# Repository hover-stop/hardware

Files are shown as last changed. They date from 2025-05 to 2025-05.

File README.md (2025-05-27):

# HSI Mk1 Hardware Repository

This repository contains the hardware design files for the HoverStop project. It includes part files, metadata, and utility scripts to manage and validate the hardware components.

---

## Documentation

For detailed design guidelines, part requirements, and contribution processes, please visit our [documentation site](https://hover-stop.github.io/docs/).

---

## Repository Structure

Each part is stored in its own folder named with a 5-digit part number. The folder contains:

- Design files (e.g., `.step`, `.3mf`)
- `metadata.yaml` file with part details
- Optional `REQUIREMENTS.md` file for part-specific requirements

---

## Utility Scripts

The `utils/` directory contains scripts to automate common tasks:

- **`cli_new_part.py`**: Automates the creation of new part directories with unique part numbers.
- **`cli_make_bom.py`**: Generates a Bill of Materials (`BOM.md`) from all `metadata.yaml` files.
- **`cli_validate_metadata.py`**: Validates `metadata.yaml` files against a defined schema.

Refer to the `utils/README.md` file for setup and usage instructions.

---

## Contribution Workflow

1. Create a new branch for your changes.
2. Use `cli_new_part.py` to add new parts.
3. Validate your changes with `cli_validate_metadata.py`.
4. Generate the BOM using `cli_make_bom.py`.
5. Submit a pull request for review.

---

## Communication

All major updates and discussions are coordinated via Discord. For questions or support, please reach out to the team.

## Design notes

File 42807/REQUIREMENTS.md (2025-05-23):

# Requirements for 42807 - Case Adapter (formerly "Mounting Tray" / "Purple Brace")

This document outlines the key design and functional requirements for the **Case Adapter** (Part Number 42807), previously referred to as the "mounting tray" or "purple brace". This adapter is used only when the HSI Mk.1 throttle is enclosed within the HSI case, and serves as the interface between the throttle base plate and the case walls.

## Functional Requirements

1. **Case-to-Throttle Interface:** Shall provide a structural interface between the HSI Mk.1 **Base Plate** (to which all throttle components are mounted) and the **case walls**, enabling the throttle to be enclosed.
2. **Used Only with Case:** This adapter is only used when the throttle is mounted **within the HSI case**. It is not compatible with DZUS rail mounting or standalone tray installations.
3. **Supports Base Plate:** Provides support under the **Base Plate**, but does not directly attach to the throttle internals (`96784 - Body Assembly`)—only the plate beneath them.
4. **Serviceability:** Must allow for installation and removal of the base plate and case walls without damage or interference.
5. **Clearance for Components:** Must allow adequate clearance beneath the base plate for connectors, wiring, or hardware.

## Physical & Manufacturing Requirements

1. **3D Printability:** Must be manufacturable as a single 3D-printed part on a print bed of at least 256x256mm.
2. **Material:** Recommended materials include PETG, ABS, or similar with sufficient structural rigidity.
3. **Dimensional Fit:** Must align with the base plate footprint and internal volume defined by the `77875 - Ghost Volume, Throttle Body`.

## Assembly & Hierarchy

1. **Parent Assembly:** Component of `62988 - HSI Mk.1 Mounting Kit`.
2. **Mounting Method:** Attaches between the **Base Plate** and the **case walls**, enabling enclosure use only.

## Naming and Clarification

* This part shall be referred to as the **Case Adapter**.
* It is **not** to be confused with the **Base Plate**, which directly supports the throttle hardware.
* It is **not** used in installations involving:
  - **DZUS rails**
  - **Standalone trays**
  - **Direct mounting to a cockpit panel or desktop**

## Exclusions

* Not used when the HSI Mk.1 throttle is mounted using DZUS rails.
* Not used when mounted to a standalone tray or open frame.
* Not a substitute for the Base Plate or Body Assembly.

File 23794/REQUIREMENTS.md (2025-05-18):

# Requirements for 23794 - Angle Sensor, Hall Effect

This document outlines the key design and functional requirements for the P3022 Hall Effect Angle Sensor (Part Number 23794).

## Functional Requirements

1. **Measurement Function:** Must provide precise, non-contact rotary position measurement for the throttle axes.
2. **Sensing Range:**
   * Primary Option (P3022C360V1T): 0-360° continuous rotation measurement
   * Alternative Option (P3022C90V1T): 0-90° limited rotation measurement
3. **Output Characteristics:**
   * Signal Type: Analog voltage output proportional to angle
   * Resolution: High precision, suitable for flight control input detection
   * Response Time: Fast enough for real-time flight simulator control input
4. **Electrical Specifications:**
   * Supply Voltage: Compatible with controller board (typically 5V DC)
   * Output Range: 0-5V proportional voltage output
   * Current Consumption: Low power consumption suitable for extended operation

## Physical & Manufacturing Requirements

1. **Form Factor:** Miniature size to fit within confined throttle mechanism spaces
2. **Mounting Interface:** 
   * Must be mechanically compatible with the HSI Mk.1 throttle axis mounting points
   * Installation must allow proper alignment with the rotation axes
3. **Dimensions:** As per P3022 series specifications
4. **Shaft/Magnet Interface:** Compatible with the throttle control axes

## Durability & Performance Requirements

1. **Lifespan:** Minimum 100,000 rotation cycles without calibration drift
2. **Mechanical Durability:** 
   * No-contact measurement to prevent mechanical wear
   * Shaft bearings (if applicable) must support smooth operation
3. **Temperature Range:** Suitable for indoor operation (0°C to 50°C minimum)
4. **Linearity:** High linearity across the measurement range

## Integration Requirements

1. **Electrical Interface:** Compatible with the HSI Mk.1 controller board
2. **Wiring:** Standardized connector or wire leads for integration with the `81137 - Wiring Harness`
3. **Calibration:** Easily calibratable in-situ 
4. **Mechanical Integration:**
   * Must be installable on all three measurement axes (throttle, nozzle position, and friction control)
   * Mounting orientation must be consistent with the sensor's measurement plane

## Usage Applications

These sensors will be installed in the following control axes:
1. Main throttle position measurement
2. Nozzle position control measurement
3. Possibly friction control or other auxiliary axis measurement

## Assembly & Hierarchy

1. **Parent Assembly:** This part is a component of `51364 - Sensors Kit`
2. **Quantity per Assembly:** 3 units (one per axis of measurement)
3. **Installation Sequence:** To be installed during final assembly of the respective control mechanisms

## Sourcing Options

1. **Primary Source:** CALT P3022C360V1T from manufacturer website (https://caltsensor.com/product/miniature-non-contact-angle-sensor-p3022-series/)
2. **Secondary Source:** Alternative supplier via Amazon (https://a.co/d/a8b02RU)
3. **Alternatives:** The P3022C90V1T may be substituted if the 360-degree measurement range is not required for a particular axis

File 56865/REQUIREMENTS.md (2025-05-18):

# Requirements for 56865 - Toggle Switch, 2 Position

This document outlines the key design and functional requirements for the Toggle Switch (Part Number 56865).

## Functional Requirements

1. **Switch Type:** 2-position maintained toggle switch
2. **Electrical Specifications:**
   * Configuration: SPST-NO (Single Pole, Single Throw, Normally Open)
   * Current Rating: 6A minimum
   * Number of Terminals: 2

3. **Function-Specific Requirements:**
   * **When Used for Manual Fuel Control:**
     * 2-Position Lever Lock Toggle
     * Release Force: 3-6 lb
     * Operating Force: 8 lb maximum
     * Actuation Angle: 21.5° ± 0.06°

   * **When Used for Jet Pipe Temp Limit (JPTL):**
     * 2-Position Toggle Switch
     * Operating Force: 28 oz + 8 oz (36 oz maximum)
     * Actuation Angle: 16° ± 1°

## Physical & Manufacturing Requirements

1. **Form Factor:** Round toggle
2. **Material:** Per manufacturer specification, suitable for cockpit environment
3. **Mounting:** Panel mount compatible with standard cockpit panel thickness
4. **Durability:** Must withstand repeated actuations without degradation of performance

## Interfacing Requirements

1. **Electrical Connection:** Compatible with standard aircraft electrical systems
2. **Panel Integration:** Must conform to standard panel cutout dimensions
3. **Terminal Accessibility:** Terminals must be accessible for secure wire connection

## Environmental Requirements

1. **Operating Temperature Range:** Suitable for cockpit environment (-20°C to +70°C)
2. **Humidity Resistance:** Capable of operation in varying humidity conditions

## Alternatives & Sourcing

1. **Commercial Alternative:** 
   * McMaster-Carr 7343K184 or Digikey TA2-1A-DC-5 
   * These parts are interchangeable for both functions

2. **MIL-SPEC Alternatives:** 
   * For Jet Pipe Temp Limit (JPTL): MS24523-22
   * For Manual Fuel Control: MS24658-22G
   * Note: MIL-SPEC parts are not interchangeable between functions

## Assembly & Hierarchy

1. **Parent Assembly:** This part is a component of `51364 - Sensors Kit`
2. **Quantity per Assembly:** 2 units (one for Manual Fuel Control, one for JPTL)

## Compliance

1. **Standards:** Should meet or exceed the requirements from the Air Crew Stations specification document
2. **Ergonomic Performance:** Operating forces and actuation angles must match specifications to provide authentic simulator control feel

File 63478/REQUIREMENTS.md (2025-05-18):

# Requirements for 63478 - Toggle Switch, 3 Position

This document outlines the key design and functional requirements for the 3-Position Toggle Switch (Part Number 63478).

## Functional Requirements

1. **Switch Type:** 3-position momentary toggle switch
2. **Electrical Specifications:**
   * Configuration: DPDT (Double Pole, Double Throw)
   * Current Rating: 6A minimum
   * Voltage Rating: 28VDC
   * Number of Terminals: 6

3. **Function-Specific Requirements for Rudder Trim:**
   * Momentary return to center (spring-loaded)
   * Operating Force: 20-24 oz
   * Actuation Angle: 17° ± 1° each side from center position
   * Center detent force: 8-10 oz
   * Return-to-center spring force: Must return to center position when released from either extreme

## Physical & Manufacturing Requirements

1. **Form Factor:** Round toggle with IP67 rating
2. **Material:** Per manufacturer specification, suitable for cockpit environment
3. **Mounting:** Panel mount compatible with standard cockpit panel thickness (0.125" - 0.187")
4. **Durability:** Must withstand 100,000 actuations minimum without degradation of performance

## Interfacing Requirements

1. **Electrical Connection:** Solder lugs or quick-connect terminals
2. **Panel Integration:** 0.5" (12.7mm) mounting hole
3. **Terminal Accessibility:** Terminals must be accessible for secure wire connection
4. **Labeling:** Must accommodate NOSE UP/NOSE DOWN labeling on panel

## Environmental Requirements

1. **Operating Temperature Range:** -30°C to +85°C
2. **Humidity Resistance:** IP67 rated or equivalent
3. **Vibration Resistance:** Must maintain functionality under typical cockpit vibration conditions

## Alternatives & Sourcing

1. **Commercial Alternative:** 
   * McMaster-Carr 6D1-003
   * Digikey 3-position momentary toggle switch with DPDT configuration
   * These parts must be verified for correct return-to-center spring functionality

2. **MIL-SPEC Alternative:** 
   * MS24524-27
   * Note: This is the original specification part used in aircraft

## Assembly & Hierarchy

1. **Parent Assembly:** This part is a component of `51364 - Sensors Kit`
2. **Quantity per Assembly:** 1 unit (for Rudder Trim control)

## Compliance

1. **Standards:** Should meet or exceed the requirements from the Air Crew Stations specification document
2. **Ergonomic Performance:** Operating forces and actuation angles must match specifications to provide authentic simulator control feel
3. **Operational Feel:** Must provide positive tactile feedback when moved away from center position

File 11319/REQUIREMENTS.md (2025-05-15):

# Requirements for 11319 - Throttle Body Bottom Plate

This document outlines the key design and functional requirements for the Throttle Body Bottom Plate (Part Number 11319).

## Functional Requirements

1.  **Structural Base:** Shall serve as the primary structural base for the `96784 - HSI Mk.1 Body Assembly`.
2.  **Component Mounting:** Must provide robust and accurate mounting points for:
    *   Top facia panels.
    *   Internal throttle mechanisms (e.g., lever assemblies, sensors, friction systems).
    *   Any other components directly part of the core throttle body.
3.  **Load Bearing:** Must be capable of supporting the loads exerted by user operation of the throttle controls and the weight of attached components.
4.  **Serviceability:** Design should allow for access to and servicing of internal components attached to this plate.

## Physical & Manufacturing Requirements

1.  **Primary Manufacturing Process:** Intended to be `3D Printed` (as per metadata). Alternative manufacturing considerations can be noted if applicable.
2.  **Material:** To be specified (e.g., PETG, ABS, PLA+ with sufficient strength and rigidity).
3.  **Dimensional Stability:** Must maintain dimensional accuracy to ensure proper fit and alignment of all attached parts and external mounting interfaces.
4.  **Heat Resistance:** If in proximity to electronics or other heat sources, material selection should consider heat resistance.

## Interfacing & Mounting Requirements

This plate is designed for versatile mounting and must provide features to interface with the following (mutually exclusive mounting methods):

1.  **Enclosure Mounting (via `42807 - Mounting Tray`):**
    *   Shall provide defined mounting points (e.g., holes, bosses) to securely attach to the `42807 - Mounting Tray` (the "purple brace").
    *   These mounting points must align with the corresponding features on the `42807 - Mounting Tray`.
2.  **DZUS Rail Mounting:**
    *   Shall incorporate features compatible with standard DZUS rails for direct mounting (if this option is chosen).
    *   This may include specific hole patterns, thicknesses, or edge features.
3.  **Custom Flat Panel Mounting:**
    *   Shall provide a pattern of mounting holes (e.g., 6 or more, as per Xpendable's notes) allowing it to be screwed down onto a custom flat surface (e.g., wood, MDF, metal plate).
    *   These holes should be accessible from the top (through the facia or before facia installation).
    *   The design should consider necessary cutouts in the custom panel for throttle mechanism clearance, mimicking openings in the `42807 - Mounting Tray`.

## Assembly & Hierarchy

1.  **Parent Assembly:** This part is a critical component of `96784 - Body Assembly`.
2.  **Fastening Methods:** Should utilize appropriate fastening methods for all attached components (e.g., heat-set inserts for machine screws, self-tapping screws for plastic if suitable, through-holes for bolts).

## Design Considerations

*   Minimize weight while maintaining structural integrity.
*   Ensure clearance for all moving parts of the throttle mechanisms.
*   Consider wire routing and management if electronics are mounted directly or pass through.

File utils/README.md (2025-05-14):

# Utility Scripts

This directory contains utility scripts to help manage and automate tasks within the hardware project.

## Environment Setup (One-time)

Before running any utility scripts for the first time, you need to set up a Python virtual environment and install the required packages. This ensures that the scripts run in an isolated environment with the correct dependencies.

1.  **Open your terminal or command prompt.**
2.  **Navigate to the `utils` directory** within this project:
    ```sh
    cd path\to\hardware\utils
    ```
3.  **Create the virtual environment:**
    ```sh
    python -m venv .venv
    ```
    This will create a new folder named `.venv` in the `utils` directory.
4.  **Activate the virtual environment:**
    *   On Windows (PowerShell):
        ```powershell
        .\.venv\Scripts\Activate.ps1
        ```
    *   On Windows (Command Prompt):
        ```cmd
        .\.venv\Scripts\activate.bat
        ```
    *   On macOS and Linux:
        ```sh
        source .venv/bin/activate
        ```
    Your terminal prompt should change to indicate that the virtual environment is active (e.g., `(.venv) ...`).
5.  **Install required packages:**
    With the virtual environment active, run the following command to install the necessary Python libraries:
    ```sh
    pip install PyYAML jsonschema
    ```

You only need to perform these setup steps once. For subsequent uses, you just need to activate the virtual environment (step 4) before running a script.

## `cli_new_part.py`

### Purpose

The `cli_new_part.py` script is a command-line tool designed to streamline the creation of new part entries in this repository. It automates the process of:

1.  Generating a unique 5-digit part number.
2.  Creating a new directory for the part, named with this part number.
3.  Generating a `metadata.yaml` file within the new part directory, pre-filled with information provided by the user via interactive prompts.

This helps ensure consistency and reduces manual effort when adding new hardware components.

### How to Use

1.  **Open your terminal or command prompt.**
2.  **Navigate to the `utils` directory** within this project:
    ```sh
    cd path\to\hardware\utils
    ```
3.  **Activate the Python virtual environment** (if not already active):
    *   On Windows (PowerShell):
        ```powershell
        .\.venv\Scripts\Activate.ps1
        ```
    *   On Windows (Command Prompt):
        ```cmd
        .\.venv\Scripts\activate.bat
        ```
    *   On macOS and Linux:
        ```sh
        source .venv/bin/activate
        ```
4.  **Run the script** using Python:
    ```sh
    python cli_new_part.py
    ```
5.  **Follow the prompts:** The script will ask you for various details about the new part, such as owner, name, description, etc. Provide the information as requested.
6.  Once all information is gathered, the script will create the new part directory and its `metadata.yaml` file in the main `hardware` directory (one level above `utils`).
7.  **Deactivate the virtual environment** when you are done (optional but good practice):
    ```sh
    deactivate
    ```

Example: If the script generates part number `12345`, it will create a directory `../12345/` and `../12345/metadata.yaml`.

## `cli_validate_metadata.py`

### Purpose

The `cli_validate_metadata.py` script is a command-line tool used to validate all `metadata.yaml` files within the project against a defined schema. This helps ensure consistency and correctness of the metadata across all parts.

The script checks for:
1.  Correct YAML format.
2.  Adherence to a predefined schema (e.g., required fields, correct data types, allowed values for certain fields like `status` and `part_type`).
3.  Consistency between the `part_number` field in the `metadata.yaml` file and its parent directory name.

### How to Use

1.  **Ensure `jsonschema` is installed:** If you haven't already, install it with the virtual environment active:
    ```sh
    pip install jsonschema
    ```
2.  **Open your terminal or command prompt.**
3.  **Navigate to the `utils` directory** within this project:
    ```sh
    cd path\to\hardware\utils
    ```
4.  **Activate the Python virtual environment** (if not already active - see Environment Setup).
5.  **Run the script** using Python:
    ```sh
    python cli_validate_metadata.py
    ```
6.  The script will output the validation status for each `metadata.yaml` file found. If errors are present, they will be detailed, indicating the file, the location of the error within the file, and the nature of the error.
7.  A summary of the validation results will be printed at the end.
8.  **Deactivate the virtual environment** when you are done (optional but good practice):
    ```sh
    deactivate
    ```

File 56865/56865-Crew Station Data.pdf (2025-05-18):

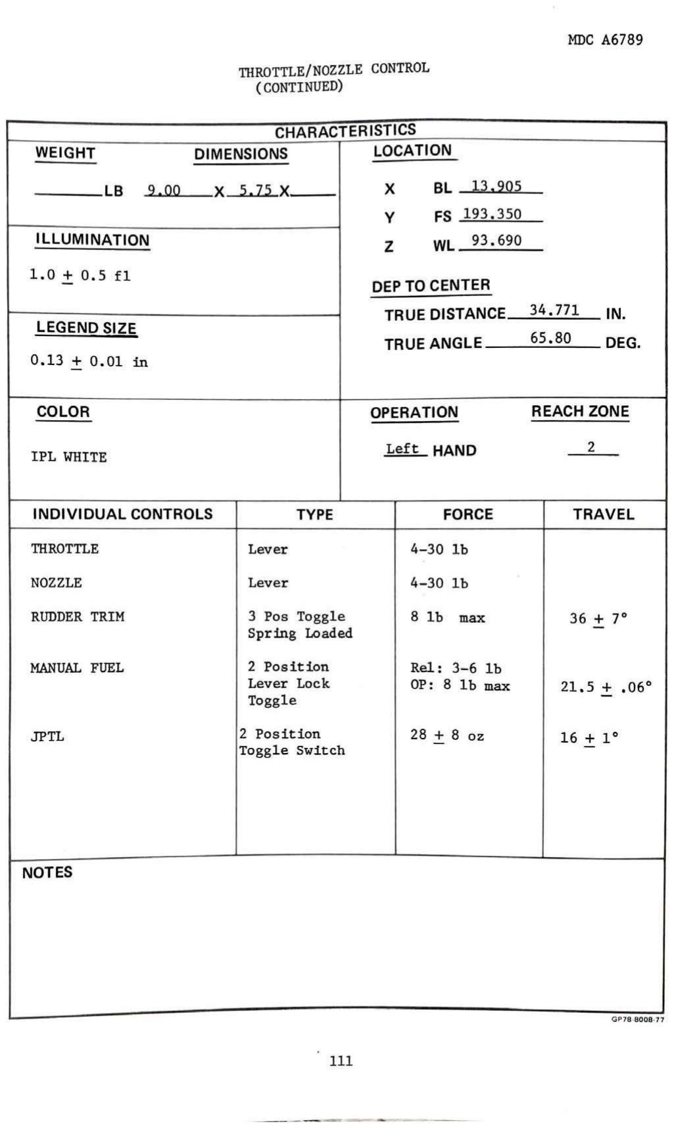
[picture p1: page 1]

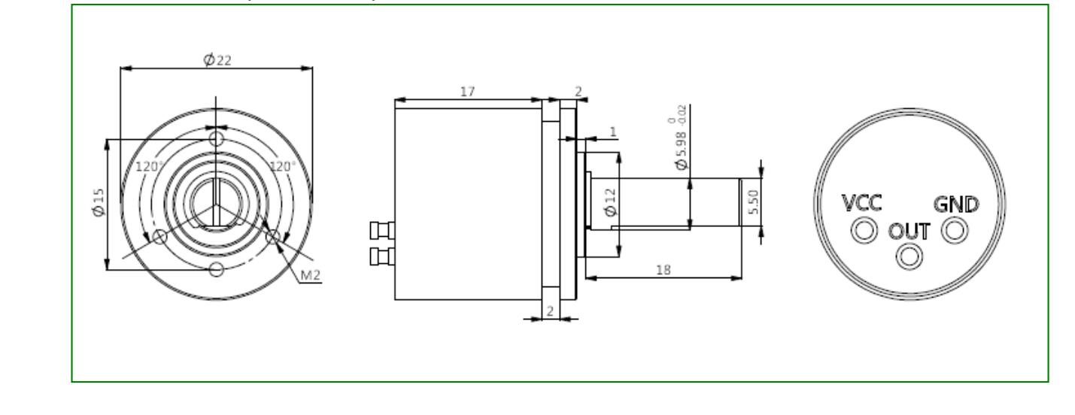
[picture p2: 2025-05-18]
23794/P3022C360V1T.jpg

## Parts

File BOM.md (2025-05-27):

<!-- 
THIS FILE IS AUTO-GENERATED BY THE cli_make_bom.py SCRIPT.
DO NOT EDIT THIS FILE MANUALLY. YOUR CHANGES WILL BE OVERWRITTEN.
-->

# Bill of Materials

Generated on: 2025-05-26

| Part Number | Name | Description | Qty | Part Type | Primary Source | Cost | Owner | Status |
| --- | --- | --- | --- | --- | --- | --- | --- | --- |
| 11117 | Electronics Assembly | Assembly of all electronic components, sensors, controllers, and wiring harnesses for the HSI Mk.1. | 1 | Assembly | In-house design | TBD | Engines | Draft |
| 11319 | Throttle Body Bottom Plate | Structural base of the HSI Mk.1 throttle body. Top facia panels and internal mechanisms attach to this plate. Designed for multiple mounting options: via 42807 Mounting Tray (for enclosures), DZUS rails, or custom flat panel. | 1 | 3D Printed | In-house design | TBD | Xpendable | Draft |
| 12574 | Hex Head Screw, M4 x 20 mm, Class 8.8, Zinc-Plated Steel | M4 × 20 mm hex-head screw, Class 8.8 steel, fully threaded (M4-0.7 mm, Class 6h, right-hand). Head width 7 mm, height 2.8 mm; ISO 4017 / DIN 933 compliant. Zinc-plated finish for mild corrosion resistance; 110 000 psi tensile strength, Rockwell C21 hardness. Cost ≈ /usr/bin/bash.02 ea (pack of 100). RoHS 3 and REACH compliant. | 6 | Off The Shelf | https://www.mcmaster.com/91280A140/ | TBD | Engines | Draft |
| 14619 | Ghost Volume, Throttle Body, Inner | A ghost part that represents the inside limits for the throttle body desgin. | 1 | Ghost | Unknown | $0.00 | Xpendable | Prototype |
| 18923 | Spur Gear, Sensor | The small spur gear that attaches to the angle sensor.  This is driven by the levers.  It has a modulus of 0.8mm and 22 teeth. | 1 | 3D Printed | Unknown | TBD | Engines | Draft |
| 18924 | Throttle Grip Comms Switch Center Button | Center button of the comms-rocker-switch of the throttle grip, designed for either 3D printing or CNC machining | 1 | 3D Printed | In-house prototype | TBD | Kurisu | Draft |
| 22357 | Support Frame, Throttle | This is the main supporting frame that locates and retains the throttle mechanism. | 1 | 3D Printed | Unknown | TBD | Engines | Draft |
| 22358 | Throttle Grip Comms Switch Rocker Switch | Rocker-switch for the comms-switch of the throttle grip, designed for either 3D printing or CNC machining | 1 | 3D Printed | In-house prototype | TBD | Kurisu | Draft |
| 23794 | Angle Sensor, Hall Effect | CALT P3022C360V1T (alt P3022C90V1T) miniature non-contact hall effect angle sensor for precision rotary position measurement. Used for axis position sensing in the HSI Mk.1. | 3 | Electronics | https://caltsensor.com/product/miniature-non-contact-angle-sensor-p3022-series/ | TBD | Engines | Release |
| 28175 | Brush, Throttle | Brush strip used to seal the opening in the throttle body where the throttle lever protrudes. | 2 | Off The Shelf | https://www.mcmaster.com/74405T1-74405T109/ | $2.75 | Engines | Release |
| 31074 | Angle Sensor, Retaining Plate | This is the plate that retains the attachment plate of the angle sensor in the throttle support frame | 1 | 3D Printed | Unknown | TBD | Engines | Draft |
| 31612 | Flat Head Screw, M8 x 25 mm, Zinc-Plated Steel | M8 × 25 mm flat-head Phillips screw, zinc-plated steel, fully threaded (M8-1.25, Class 6h, right-hand). Head Ø 14.5 mm, head height 4 mm, 90 ° countersink, DIN 965 compliant, 60 000 psi tensile strength. Provides mild corrosion resistance; RoHS 3 and REACH compliant. | 2 | Off The Shelf | https://www.mcmaster.com/91420A530/ | $0.40 | Engines | Draft |
| 32001 | Grip Chassis Part 1 | Main chassis body for the throttle grip designed for either 3D printing or CNC machining | 1 | 3D Printed | In-house prototype | TBD | Kurisu | Draft |
| 32002 | Grip Chassis Part 2 | Second part of the main chassis body for the throttle grip designed for either 3D printing or CNC machining | 1 | 3D Printed | In-house prototype | TBD | Kurisu | Draft |
| 35582 | Angle Sensor, Attachment Plate | The moving plate that retains the angle sensor when it is mounted to the frame assembly. | 1 | 3D Printed | Unknown | TBD | Engines | Draft |
| 39780 | Pan Head Screw, M4 x 30 mm, Zinc-Plated Steel | M4 x 30 mm pan head Phillips screw, zinc-plated steel, fully threaded, DIN 7985 and ISO 7045 compliant. Provides mild corrosion resistance. | 1 | Off The Shelf | https://www.mcmaster.com/92005A232/ | TBD | Engines | Draft |
| 41464 | Friction Cam Lever, Drum Brake, 3D-Printed | 3D-printed cam lever that pivots to press the brake shoes against the 66-tooth drum gear. Material: PETG or PA-CF, 4 perimeters, 40 % gyroid infill. | 2 | 3D Printed | In-house additive manufacturing | TBD | Engines | Draft |
| 42807 | Case Adapter | Case adapter (purple brace) for securing the HSI Mk.1 Body Assembly (96784) to a case. | 1 | 3D Printed | In-house design | TBD | Xpendable | Draft |
| 45193 | Wool Felt Strip, F1, 1/16" × 1/2" × 10 ft | Firm wool felt strip, Grade F1 (95 % wool). Dimensions: 1/16 in (1.6 mm) thick × 1/2 in (12.7 mm) wide × 10 ft long. Density 1 lb/yd², durometer 35A ±5, compressive load 21 psi at 10 % strain. Plain backing, off-white, –80 °F to +200 °F service, 500 psi tensile strength. Used as friction shoe lining; provides good wear and vibration damping. Cost ≈ .23 each. RoHS 3 and REACH compliant. | 1 | Off The Shelf | https://www.mcmaster.com/5051K152/ | $0.23 | Engines | Draft |
| 48793 | Spur Gear, 66 T, Drum Brake | 66-tooth spur gear (module 1.0, 20° pressure angle, 140 mm pitch Ø ≈ 70 mm pitch radius). 3 mm drum band on OD for printed friction brake shoe. Material: PETG or PA-CF, 3D-printed, face width 10 mm, reamed Ø12 mm bore with M4 setscrew flat. | 1 | 3D Printed | In-house additive manufacturing | TBD | Engines | Draft |
| 51364 | Sensors Kit | Collection of sensors used in the HSI Mk.1, including hall effect potentiometers for axis position sensing. | 1 | Assembly | In-house design | TBD | Engines | Draft |
| 56865 | Toggle Switch, 2 Position | 2-position, round, maintained, SPST-NO toggle switch with 2 terminals, 6A rating. Used for Jet Pipe Temp Limit (JPTL) and Manual Fuel Control functions in the HSI Mk.1. | 2 | Electronics | https://www.mcmaster.com/7343K184/ | 8.96 | Engines | Release |
| 57832 | Grip Assembly | Complete assembly for the HSI Mk.1 grip | 1 | Assembly | Unknown | TBD | Kurisu | Draft |
| 57833 | Throttle Grip Analog Stick Backing Plate | Backing plate to hold the analog stick of the throttle grip in place, designed for either 3D printing or CNC machining | 1 | 3D Printed | In-house prototype | TBD | Kurisu | Draft |
| 60550 | Nut, Locking, M8 | Low strength steel, zinc plated nyloc nut for M8x1.25 threads | 1 | Off The Shelf | https://www.mcmaster.com/90631A115/ | $0.10 | Engines | Release |
| 62146 | HoverStop HSI Mk.1 | The parent assembly for the HoverStop HSI Mk.1 throttle interface unit. | 1 | Assembly | Unknown | TBD | Engines | Draft |
| 62147 | Throttle Grip Side Button Backing Plate | Backing plate for the side buttons of the throttle grip, designed for either 3D printing or CNC machining | 1 | 3D Printed | In-house prototype | TBD | Kurisu | Draft |
| 62988 | Mounting Kit | Optional mounting kit for installing the HSI Mk.1 throttle (via its Body Assembly) into an enclosure. Includes the mounting tray (42807) and any associated hardware for this specific mounting method. | 1 | Assembly | In-house design | TBD | Xpendable | Draft |
| 63478 | Toggle Switch, 3 Position | 3-position, rounded, momentary, DPDT toggle switch with IP67 rating. Used for the Rudder Trim control in the HSI Mk.1. | 1 | Electronics | https://www.mcmaster.com/8002K116/ | 18.13 | Engines | Release |
| 67367 | Dzus Rail | Quick release mounting rail for Dzus fasteners | 2 | Off The Shelf | Unknown | TBD | Xpendable | Draft |
| 69806 | Bits Kit | All screws, nuts, rivets, inserts, and other consumables necessary to build the HSI Mk.1 | 1 | Assembly | Unknown | TBD | Engines | Draft |
| 74933 | Friction Shoe | Friction shoe that fits inside the friction spur gear. | 4 | 3D Printed | Unknown | TBD | Engines | Draft |
| 77875 | Ghost Volume, Throttle Body, Outer | A ghost part that represents the outside limits for the throttle body design. | 1 | Ghost | Unknown | $0.00 | Xpendable | Prototype |
| 77876 | Throttle Grip Comms Switch Backing Plate | Backing plate for the comms-rocker-switch of the throttle grip, designed for either 3D printing or CNC machining | 1 | 3D Printed | In-house prototype | TBD | Kurisu | Draft |
| 81137 | Wiring Harness | Complete wiring harness for connecting all electronic components and sensors in the HSI Mk.1. | 1 | Cable or Wire | In-house design | TBD | Engines | Draft |
| 87883 | Flat Head Screw, M4 x 10 mm, Zinc-Plated Steel | M4 x 10 mm flat head Phillips screw, zinc-plated steel, fully threaded, DIN 965 compliant. Provides mild corrosion resistance and is designed to sit flush in countersunk holes. | 4 | Off The Shelf | https://www.mcmaster.com/91420A220/ | TBD | Engines | Draft |
| 91686 | Controller Board | Main microcontroller board for the HSI Mk.1. Responsible for reading sensor inputs and communicating with the flight simulator software. | 1 | Electronics | In-house design | TBD | Engines | Draft |
| 94961 | Hex Nut, M4, Zinc-Plated Steel | Standard hex nut, M4 × 0.7 mm coarse thread (Class 6H, right-hand). Width 7 mm, height 3.2 mm. Low-strength zinc-plated steel (DIN 934); suitable for light-duty fastening. Provides mild corrosion resistance. Cost ≈ TBD ea (pack of 100). RoHS 3 and REACH compliant. | 1 | Off The Shelf | https://www.mcmaster.com/90591A141/ | TBD | Engines | Draft |
| 96784 | Body Assembly | The body assembly for the HSI Mk.1 | 1 | Assembly | Unknown | TBD | Xpendable | Draft |
| 98415 | Ghost Parts | A collector assembly for all ghost parts used in the HSI Mk.1 | 1 | Ghost | Unknown | TBD | Engines | Draft |

## Part Assembly Tree

```
62146 - HoverStop HSI Mk.1
├── 11117 - Electronics Assembly
│   ├── 51364 - Sensors Kit
│   │   ├── 23794 - Angle Sensor, Hall Effect
│   │   ├── 56865 - Toggle Switch, 2 Position
│   │   └── 63478 - Toggle Switch, 3 Position
│   ├── 81137 - Wiring Harness
│   └── 91686 - Controller Board
├── 57832 - Grip Assembly
│   ├── 32001 - Grip Chassis Part 1
│   │   └── 62147 - Throttle Grip Side Button Backing Plate
│   └── 32002 - Grip Chassis Part 2
│       ├── 18924 - Throttle Grip Comms Switch Center Button
│       ├── 22358 - Throttle Grip Comms Switch Rocker Switch
│       ├── 57833 - Throttle Grip Analog Stick Backing Plate
│       └── 77876 - Throttle Grip Comms Switch Backing Plate
├── 62988 - Mounting Kit
│   └── 67367 - Dzus Rail
├── 69806 - Bits Kit
│   ├── 12574 - Hex Head Screw, M4 x 20 mm, Class 8.8, Zinc-Plated Steel
│   ├── 31612 - Flat Head Screw, M8 x 25 mm, Zinc-Plated Steel
│   ├── 39780 - Pan Head Screw, M4 x 30 mm, Zinc-Plated Steel
│   ├── 60550 - Nut, Locking, M8
│   ├── 87883 - Flat Head Screw, M4 x 10 mm, Zinc-Plated Steel
│   └── 94961 - Hex Nut, M4, Zinc-Plated Steel
├── 96784 - Body Assembly
│   ├── 11319 - Throttle Body Bottom Plate
│   ├── 22357 - Support Frame, Throttle
│   │   ├── 18923 - Spur Gear, Sensor
│   │   ├── 28175 - Brush, Throttle
│   │   ├── 31074 - Angle Sensor, Retaining Plate
│   │   ├── 35582 - Angle Sensor, Attachment Plate
│   │   ├── 41464 - Friction Cam Lever, Drum Brake, 3D-Printed
│   │   ├── 45193 - Wool Felt Strip, F1, 1/16" × 1/2" × 10 ft
│   │   ├── 48793 - Spur Gear, 66 T, Drum Brake
│   │   └── 74933 - Friction Shoe
│   └── 42807 - Case Adapter
└── 98415 - Ghost Parts
    ├── 14619 - Ghost Volume, Throttle Body, Inner
    └── 77875 - Ghost Volume, Throttle Body, Outer
```

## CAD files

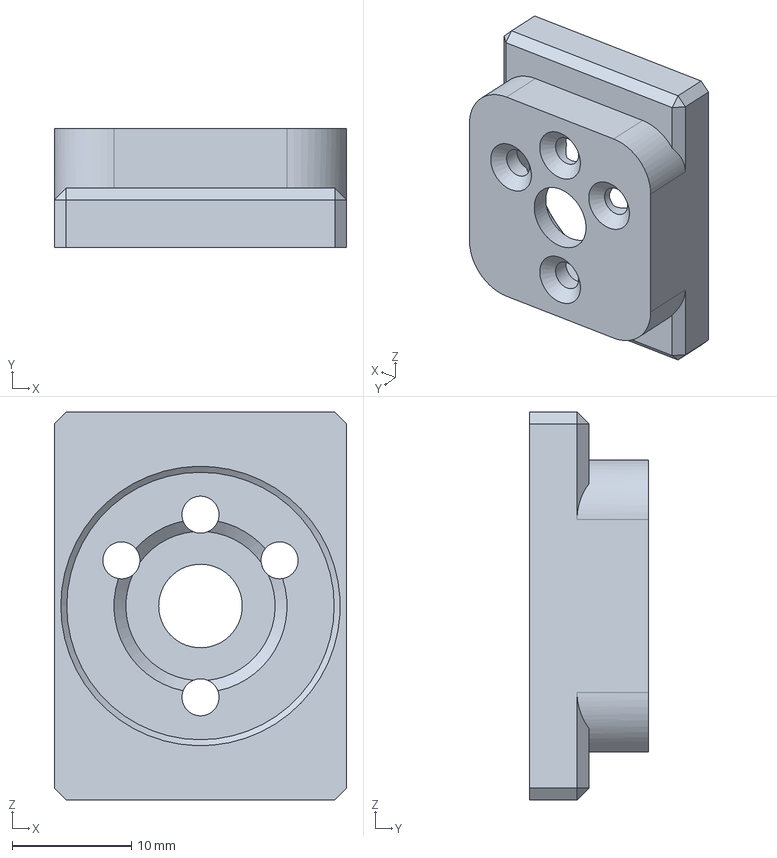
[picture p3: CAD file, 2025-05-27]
35582/Angle Sensor, Attachment Plate v2.step
24.5 x 10.0 x 32.5 mm

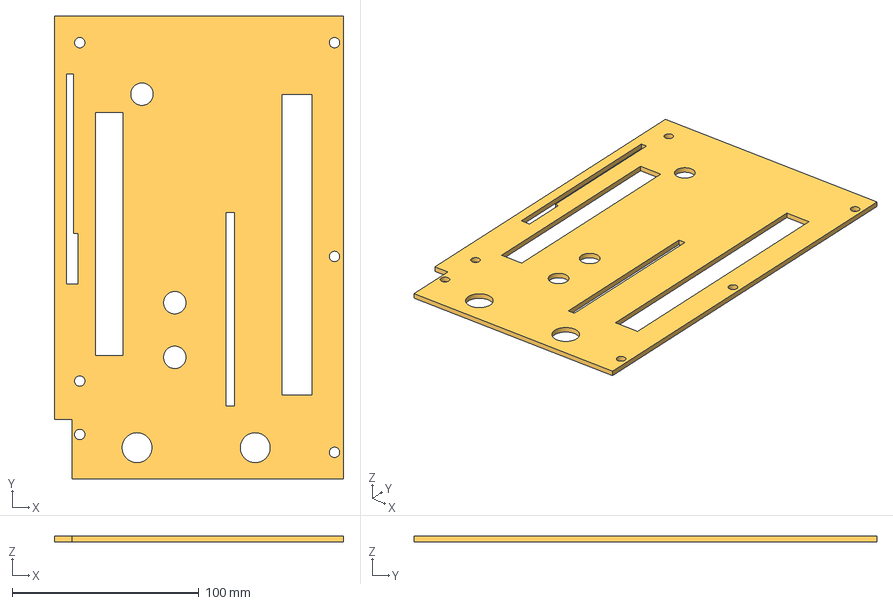
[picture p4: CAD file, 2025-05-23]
11319/11319 Throttle Body Bottom Plate.step
154.8 x 247.7 x 3.00 mm

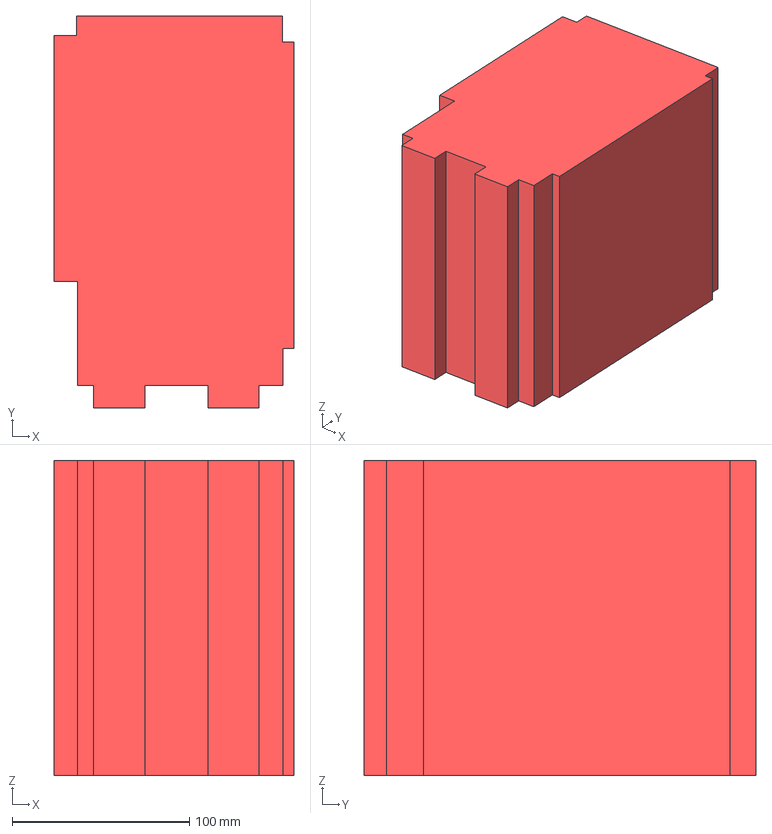
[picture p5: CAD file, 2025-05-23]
14619/14619 Ghost Volume, Throttle Body, Inner.step
135.3 x 221.3 x 177.8 mm

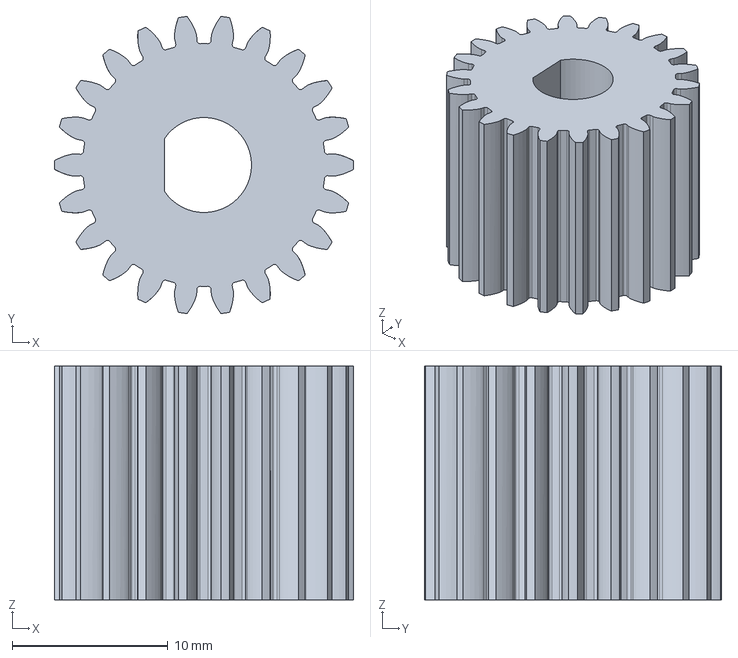
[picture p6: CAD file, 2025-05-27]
18923/18923 Spur Gear, Sensor.step
19.2 x 19.1 x 15.0 mm

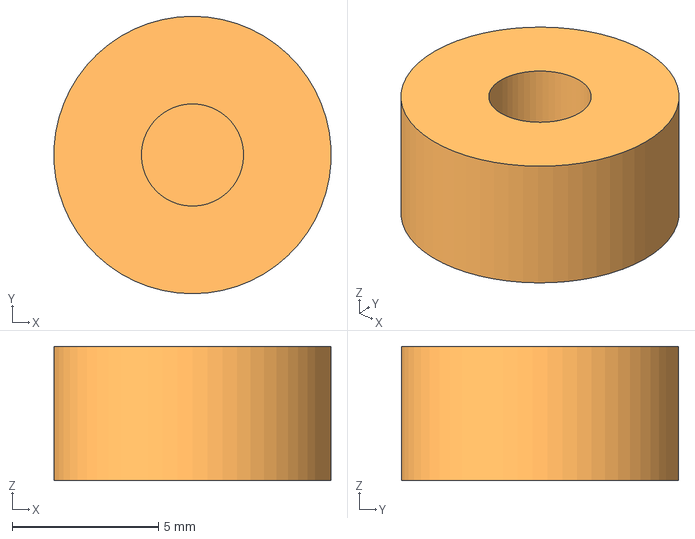
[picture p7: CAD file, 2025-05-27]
18924/18924 Throttle Grip Comms Switch Center Button.step
9.49 x 9.50 x 4.60 mm

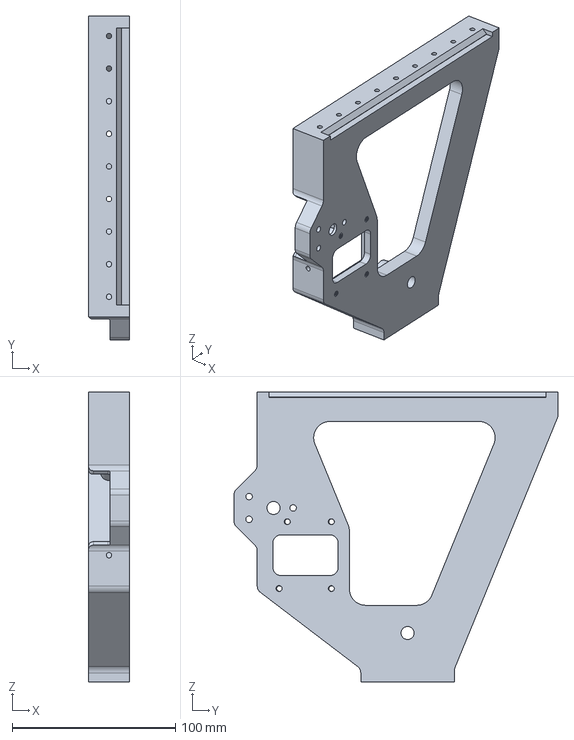
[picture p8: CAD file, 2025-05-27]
22357/22357 Support Frame, Throttle.step
25.0 x 198.8 x 177.8 mm

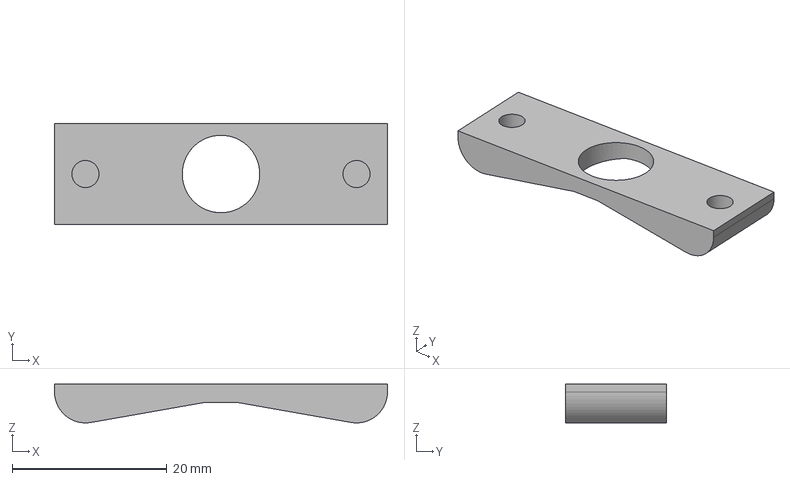
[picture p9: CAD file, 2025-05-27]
22358/22358 Throttle Grip Comms Switch Rocker Switch.step
43.0 x 13.0 x 5.02 mm

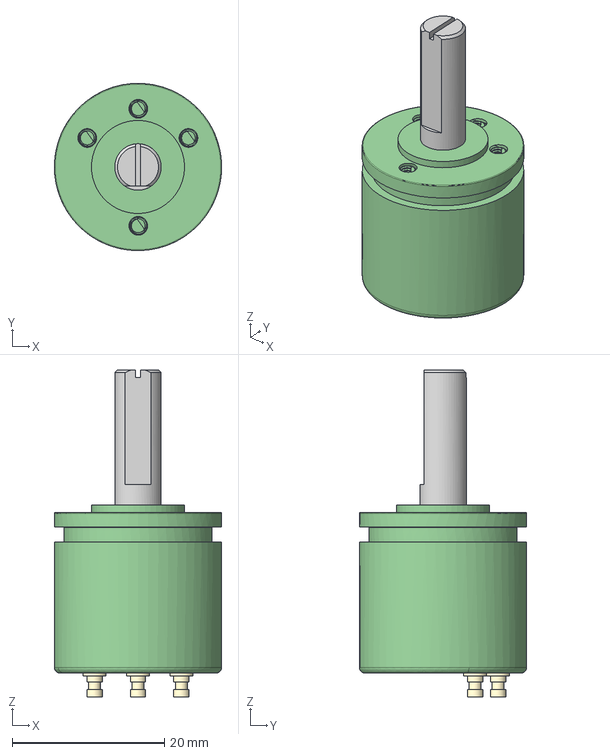
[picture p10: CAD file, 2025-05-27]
23794/23794-Angle Sensor, Hall Effect.step
22.0 x 22.0 x 43.0 mm

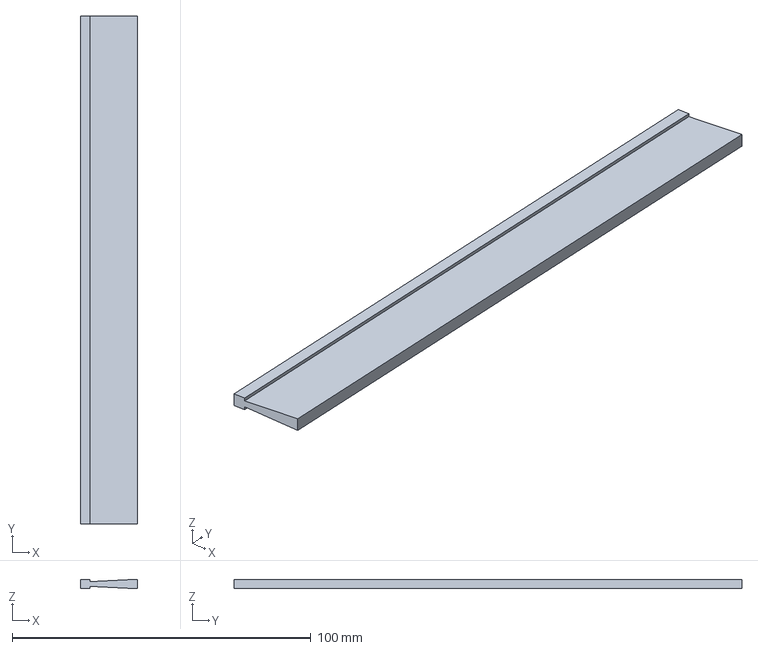
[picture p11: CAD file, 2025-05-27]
28175/28175 Brush, Throttle v1.step
19.1 x 170.0 x 3.18 mm

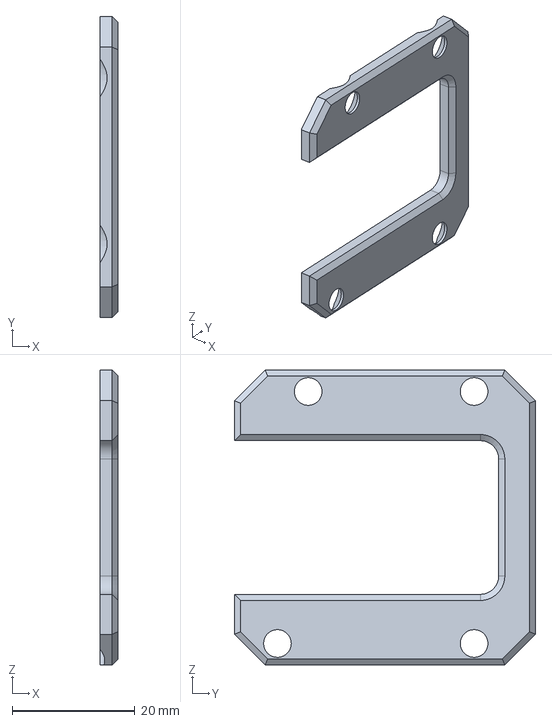
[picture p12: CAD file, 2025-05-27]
31074/31074 Angle Sensor, Retaining Plate.step
3.00 x 49.0 x 48.0 mm

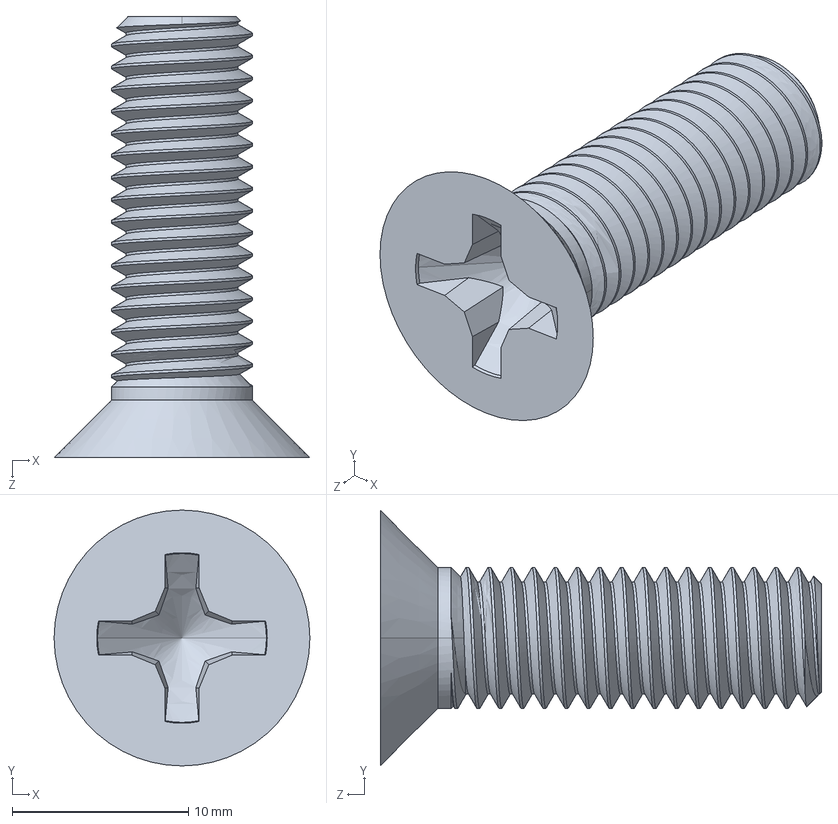
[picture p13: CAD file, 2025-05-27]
31612/31612 Flat Head Screw, M8 x 25 mm, Zinc-Plated Steel.STEP
14.5 x 14.5 x 25.0 mm

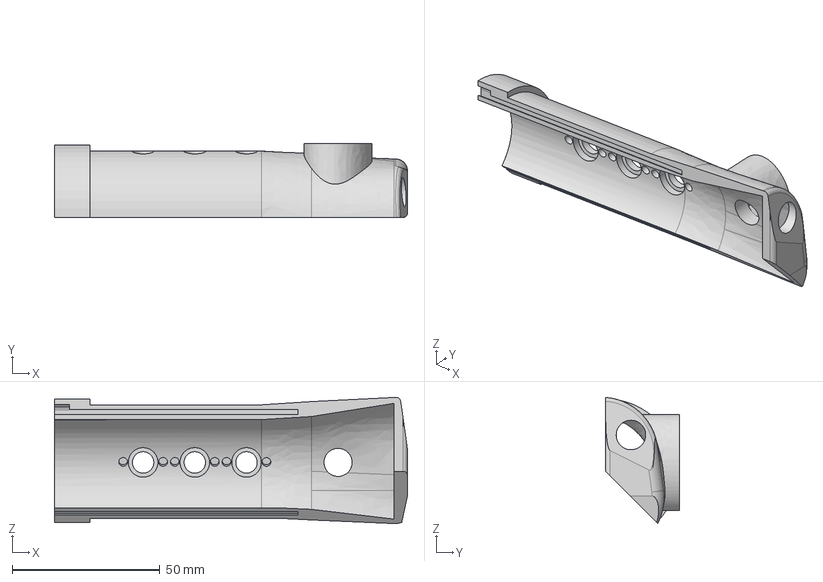
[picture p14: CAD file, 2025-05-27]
32001/32001-Grip Chassis.step
119.5 x 25.0 x 42.7 mm

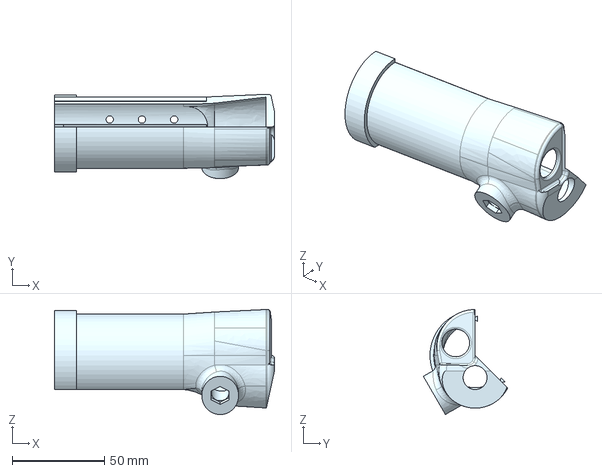
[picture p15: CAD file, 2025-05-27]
32002/32002-Grip Chassis.step
119.5 x 45.8 x 57.1 mm

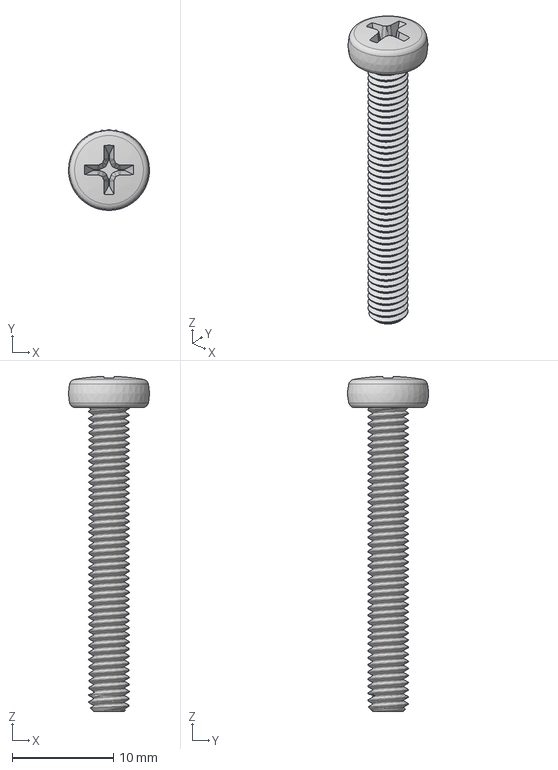
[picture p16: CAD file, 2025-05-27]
39780/39780 Pan Head Screw, M4 x 30 mm, Zinc-Plated Steel v1.step
8.00 x 7.98 x 33.1 mm

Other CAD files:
41464/41464 Friction Cam Lever, Drum Brake, 3D-Printed v6.step
42807/42807 Case Adapter.step
48793/48793 Spur Gear, 66 T, Drum Brake.step
57833/57833 Throttle Grip Analog Stick Backing Plate.step
60550/60550 Nut, Locking, M8 v1.step
62147/62147 Throttle Grip Side Button Backing Plate.step
63478/63478-Toggle Switch, 3 Position.STEP
67367/67367 Dzus Rail.step
77875/77875 Ghost Volume, Throttle Body, Outer.step
77876/77876 Throttle Grip Comms Switch Backing Plate.step
87883/87883 Flat Head Screw, M4 x 10 mm, Zinc-Plated Steel.step
98415/98415 Ghost Parts.step

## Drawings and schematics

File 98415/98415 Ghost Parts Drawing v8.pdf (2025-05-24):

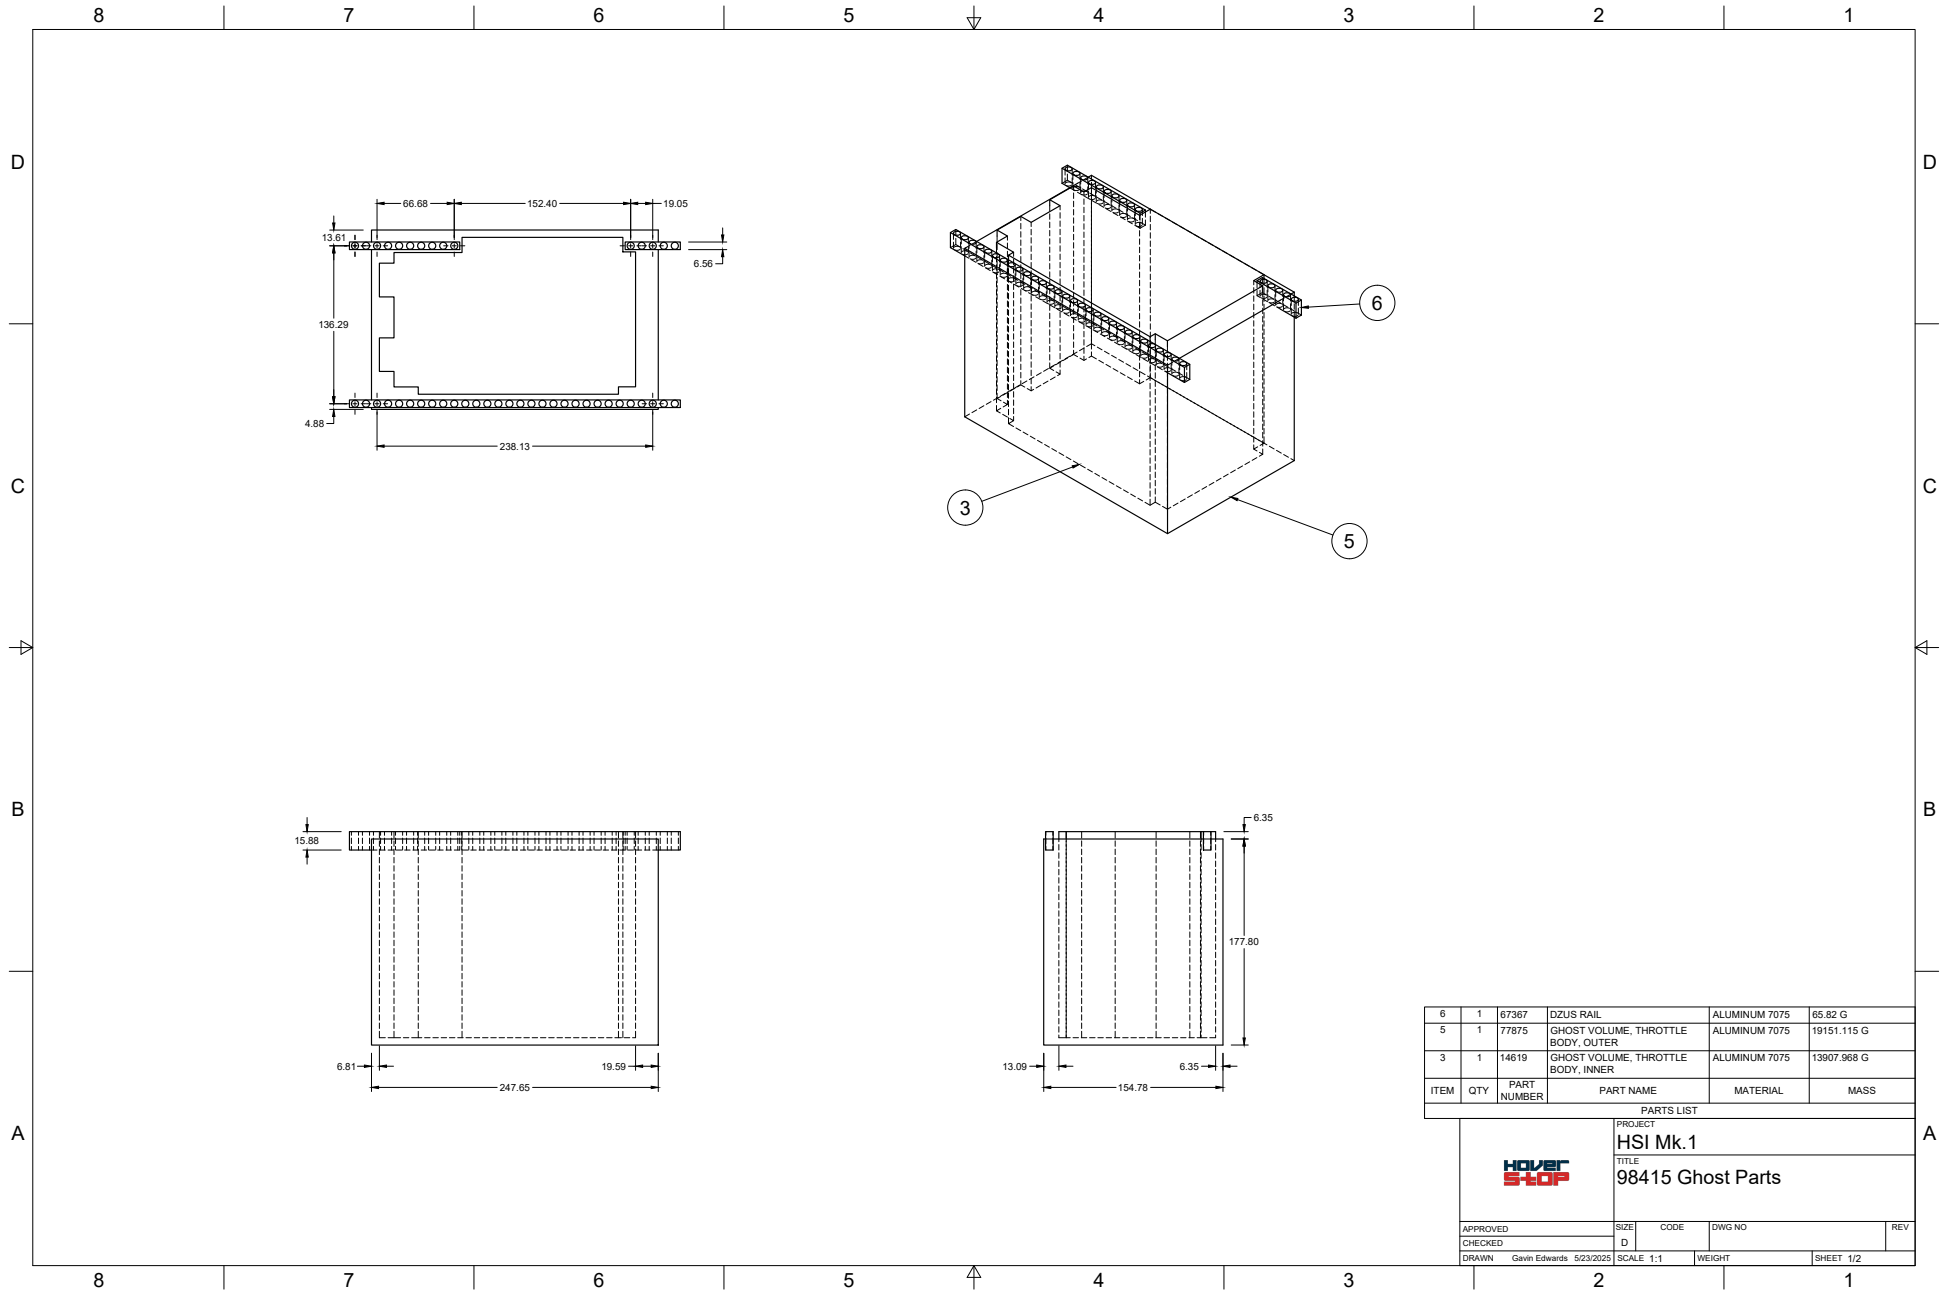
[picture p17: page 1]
SIZE; CODE; DWG NO; REV; Gavin Edwards 5/23/2025; HSI Mk.1; 98415 Ghost Parts; PARTS LIST

6 | 1 | 67367 | DZUS RAIL | ALUMINUM 7075 | 65.82 G
5 | 1 | 77875 | GHOST VOLUME, THROTTLE BODY, OUTER | ALUMINUM 7075 | 19151.115 G

3 | 1 | 14619 | GHOST VOLUME, THROTTLE BODY, INNER | ALUMINUM 7075 | 13907.968 G

ITEM | QTY | PART NUMBER | PART NAME | MATERIAL | MASS

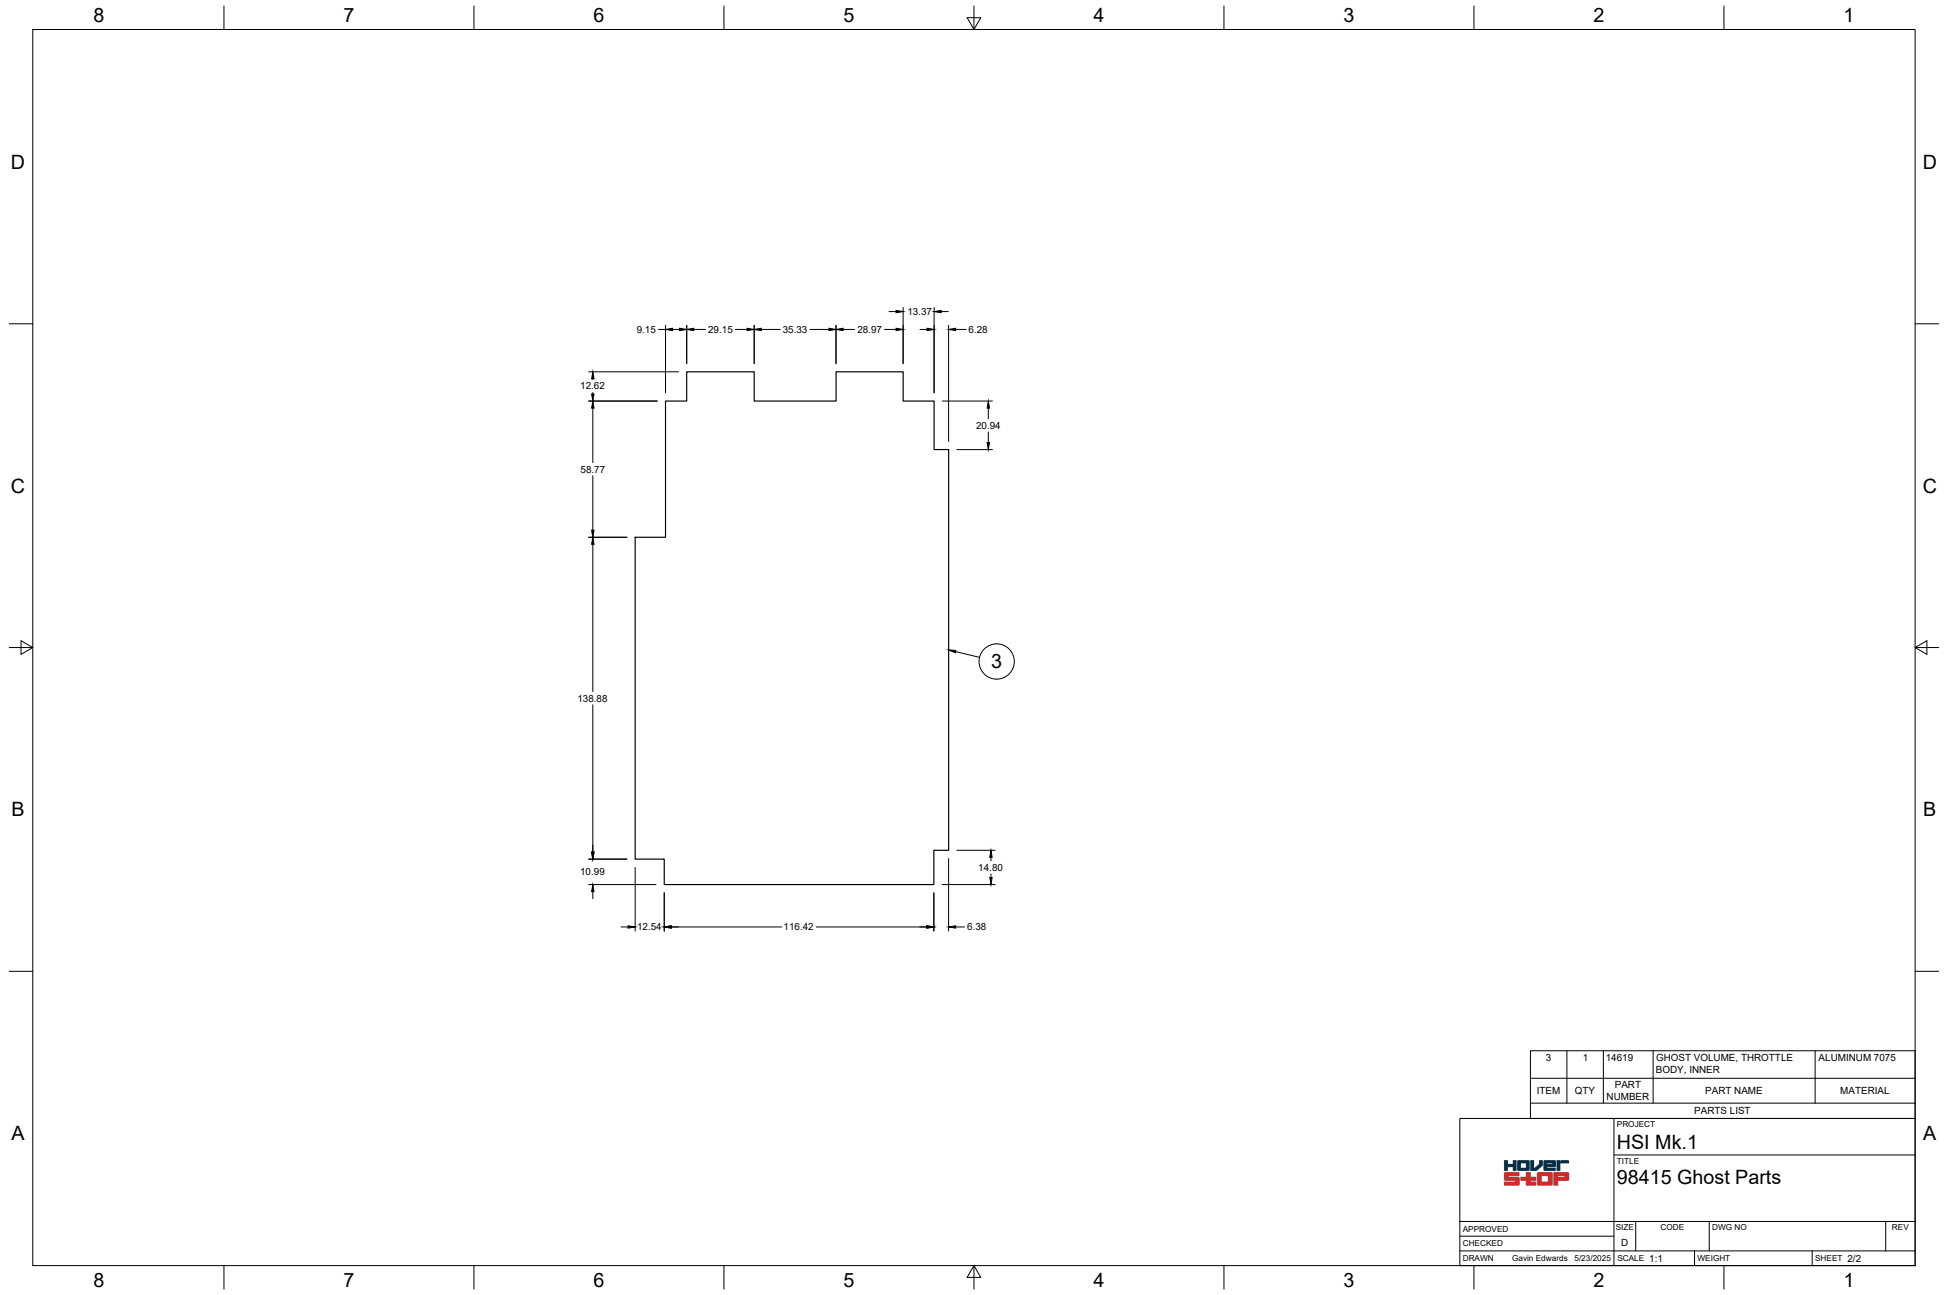
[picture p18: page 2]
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

3 | 1 | 14619 | GHOST VOLUME, THROTTLE BODY, INNER | ALUMINUM 7075

ITEM | QTY | PART NUMBER | PART NAME | MATERIAL

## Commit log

2025-05-06 Pusing the grip chassis.
    [32000-Grip Chassis.step]
2025-05-07 Adding step file witl throttle body for reference.
2025-05-08 Reworked Prototype for Throttle Grip
    Made Throttle grip shorter, moved buttons slightly and added References.pdf
    [32000-Grip Chassis.step]
2025-05-08 Revert "Reworked Prototype for Throttle Grip"
    This reverts commit 2fb68c94c4a183aa909f7f6dafbf21e12493df46.
    [32000-Grip Chassis.step]
2025-05-10 Split throttle grip in 2 parts
    [32000-Grip Chassis.step, 32001-Grip Chassis.step, 32002-Grip Chassis.step]
2025-05-14 Added bill of materials util.
2025-05-14 Adding BOM tree and initial assemblies.
2025-05-14 Updating BOM and adding part clone argument to new part tool.
2025-05-16 Create 77875 Ghost Volume, Throttle Body.step
    This reference body contains all of the usual volume below the base plate of the throttle and fits inside of DZUS rails and inside of the case enclosure option.
    [77875 Ghost Volume, Throttle Body.step]
2025-05-17 Created part number for Dzus rail and updated part name to remove redundant HSI Mk.1 from mounting and bits kit.
2025-05-18 Adding some of the switches and sensors.
    [23794-Angle Sensor, Hall Effect.stp, 63478-Toggle Switch, 3 Position.STEP]
2025-05-18 Updating the case adapter requirements.
2025-05-23 Preliminary reference files
    Initially putting these in a "to-be-filed" directory pending assignment of reference numbers.
    [77875 Base-Ghost Volume Inside.step, XXXXX Base-Case Tray.step, XXXXX Base-Combined References.step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]
2025-05-23 Pulling in the changes from Xpendable.
    [11319 Throttle Body Bottom Plate.step, 14619 Ghost Volume, Throttle Body, Inner.step, 42807 Case Adapter.step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]
2025-05-24 Updated BOM.
2025-05-25 Starting work on the support frame for the throttle.
2025-05-26 Added frame, M8 nut, and brush strip.
    [22357 Support Frame, Throttle.step, 28175 Brush, Throttle v1.step, 60550 Nut, Locking, M8 v1.step]
2025-05-26 Added & Updated Parts (see description)
    Updated 32001 and 32002 to new versions.
    Added:
    - 32003 (Analog stick backing plate)
    - 32004 (Side button backing plate)
    - 32005 (Comms backing plate)
    - 32006 (Comms center button)
    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
    [32001-Grip Chassis.step, 32002-Grip Chassis.step, 32003 - Analog Stick Backing Plate.step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]
2025-05-26 Adding step files for throttle frame components.
    [18923 Spur Gear, Sensor.step, 22357 Support Frame, Throttle.step, 23794-Angle Sensor, Hall Effect.step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]
2025-05-26 Adding screws for the friction assembly.
    [31612 Flat Head Screw, M8 x 25 mm, Zinc-Plated Steel.STEP]
2025-05-26 Fixing metadata validation errors and updating BOM.
2025-05-27 Renaming directories and step files accordingly.
    [18924 Comms Center Button.step, 22358 Comms Rocker Switch.step, 32003 - Analog Stick Backing Plate.step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]
2025-05-27 Resolving BOM conflict.
2025-05-27 Remaking the BOM.
    [18924 Throttle Grip Comms Switch Center Button.step, 22358 Throttle Grip Comms Switch Rocker Switch.step, 57833 Throttle Grip Analog Stick Backing Plate.step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]
2025-05-27 Updating BOM.
2025-05-27 Adding workflows for auto-BOM generation and metadata validation.
2025-05-27 Added mp4 version of exploded frame assembly.
2025-05-27 Adding cam lever for friction assembly.
    [41464 Friction Cam Lever, Drum Brake, 3D-Printed v6.step]
